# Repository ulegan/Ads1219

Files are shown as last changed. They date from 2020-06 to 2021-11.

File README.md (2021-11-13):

# Ads1219
A breakout board for the [ADS1219](https://www.ti.com/product/ADS1219) 24-bit AD-Converter.<br />
Size and pinout is the same as the popular ADS1x15 boards.
- Up to 1000Hz samplingrate
- Single or continuous conversion
- Single ended or differential inputs

pcb made with [KiCad](https://kicad.org/)

### Boards ordered from [OSHPARK](https://oshpark.com/)
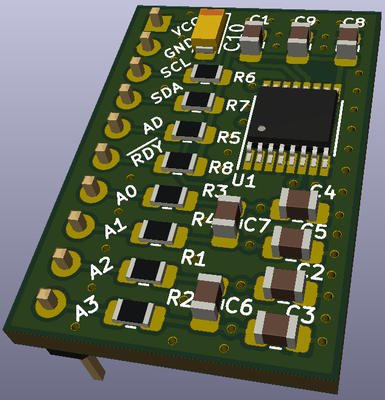
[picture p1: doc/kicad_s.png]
kicad rendering KiCad rendering
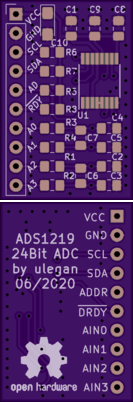
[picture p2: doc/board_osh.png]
preview OSHPARK preview
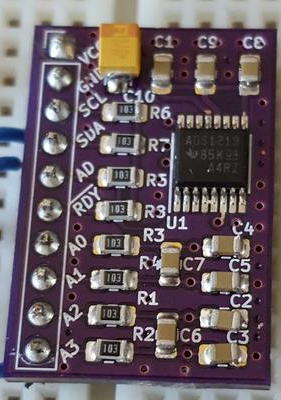
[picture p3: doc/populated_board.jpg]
first board populated board
  

### Diagramm 
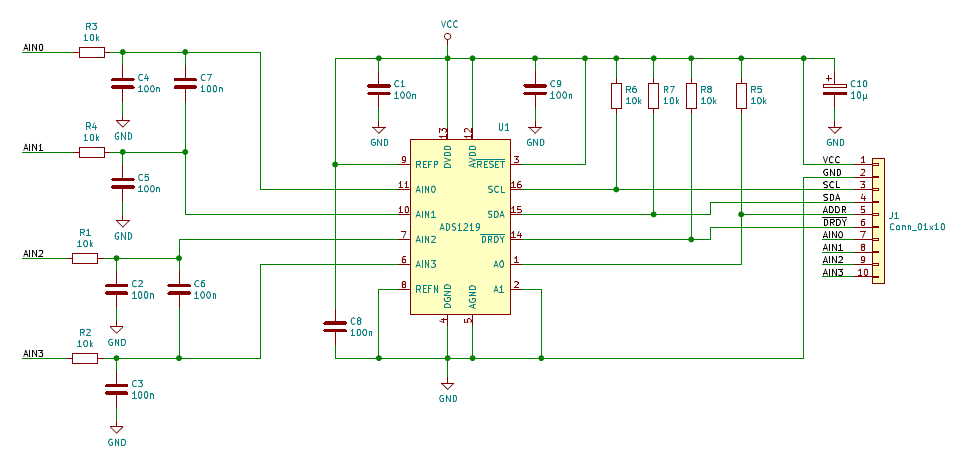
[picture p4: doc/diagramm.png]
Diagramm


If you want to use single-ended inputs, you should not use C6 and C7

### Libraries
I have written libraries for **C** and **Python** tested on a Raspberry-Pi

OM2220 wrote an [Arduino library](https://github.com/OM222O/ADS1219) for it <br />
and there is also one for [micropython](https://github.com/miketeachman/micropython-ads1219) that I have not tested yet.<br />

All libraries use the I²C-address 0x40 by default, so you have to connect the ADDR-Pin to GND, or use 0x41 in the constructor.

#### I²C-Addressing
The ADS1219 has two address-pins A0 and A1. <br />
A1 is always connected to GND, A0 has a pullup to VCC.<br />
So the I²C-ADDRESS defaults to 0x41. <br />
Four different addresses can be selected by connecting A0:

| ADDR connected to | Address |
| :--- |:---:|
| GND | 0x40 |
| VCC or open | 0x41 |
| SDA | 0x42 |
| SCL | 0x43 |

```c++

```

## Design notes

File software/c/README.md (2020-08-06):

### Prequisites
Install i2c-dev library for C
	apt-get install libi2c-dev
	
### Restrictions
Usage of RDY-pin is not supported yet

### Functions
**ads_config( mux, gain, datarate, mode, ref )**
configures the ADS1219 operating mode. Use with the constants below<br />
**ads_reset( )** resets ADS1219<br />
**ads_start( )** starts a single conversion, or starts continuous conversions<br />
**ads_powerdown( )** starts powerdown-mode, also stops conversions in continuous-mode<br />
**ads_ready( )** returns True if a new conversion result is ready 
*(reads status-register)*<br />
**ads_waitForResult( )** waits for a new conversion-result
	
### Constants to use in ads_config()
#### Constants for the input multiplexer
* **MUX_DIF_01** selects differential input pos=pin0 neg=pin1
* **MUX_DIF_23** selects differential input pos=pin2 neg=pin3
* **MUX_DIF_12** selects differential input pos=pin1 neg=pin2
* **MUX_SNG_0** selects single-ended input on pin0
* **MUX_SNG_1** selects single-ended input on pin1
* **MUX_SNG_2** selects single-ended input on pin2
* **MUX_SNG_3** selects single-ended input on pin3
* **MUX_SHORT** selects shorted differential inputs to meassure offset
#### Constants for gain selection
* **GAIN_1** input range +-2.048V with differential inputs and internal reference
* **GAIN_4** input range +-512mV with differential inputs and internal reference
#### Constants for selecting data rate
* **DR_20** sets data-rate to 20 samples per second
* **DR_90** sets data-rate to 90 samples per second
* **DR_330** sets data-rate to 330 samples per second
* **DR_1000** sets data-rate to 1000 samples per second
#### Constants for mode selection
* **MODE_SINGLESHOT** selects singleshot mode
* **MODE_CONTINUOUS** selects continuous mode
#### constants for selecting the reference voltage
* **VREF_INTERNAL** selects the internal 2.048V reference
* **VREF_EXTERNAL** selects an external reference 
### Example program test.c
````C
#include "ads1219.h"

int main() {
	int res;
	if( ( res = i2c_init(i2c_addr))<0 ) 
		printf("init failed with %d\n", res);
	ads_reset();
	ads_config(MUX_SHORT, GAIN_1, DR_20, MODE_CONTINUOUS, VREF_INTERNAL);
	ads_start();
	while(1) {
		ads_waitForReady();
		printf("%d  %d\n", time(0), ads_result());
	}
}
````
#### Compile example program with:
    cc test.c ads1219.c -otest -li2c

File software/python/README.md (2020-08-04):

### Prequisites
Install smbus2.py, because ADS1219 uses repeated start conditions, that are not supported with smbus

    pip3 install smbus2

### Constructor
**ADS1219( port=1, address=0x40, rdyPin=0 )** constructor<br />
* **port** is the I2C-port defaults to I2C1 on Pin3 (SDA) and Pin5 (SCL) on Raspberry Pi's
* **address** is the I2C-address
* **rdyPin** is the optional RDY-Pin, default: not connected

### Functions
**config( mux=MUX_DIF_01, gain=GAIN_1, datarate=DR_20, mode=MODE_SINGLESHOT, ref=VREF_INTERNAL )**
configures the ADS1219 operating mode. Use with the constants below<br />
**reset( )** resets ADS1219<br />
**start( )** starts a single conversion, or starts continuous conversions<br />
**powerdown( )** starts powerdown-mode, also stops conversions in continuous-mode<br />
**ready( )** returns True if a new conversion result is ready 
*(reads status-register)*<br />
**waitForResult( )** waits for a new conversion-result
*(uses **rdyPin** if given in constructor, or reads the status register)*<br />
**result( )** reads conversion result<br />
**callback( callbackFunction )** sets a callback function that is called, when a new conversion result is ready
*(only available if a **rdyPin** is given in the constructor)*

### Constants to use in config()
#### Constants for the input multiplexer
* **MUX_DIF_01** selects differential input pos=pin0 neg=pin1
* **MUX_DIF_23** selects differential input pos=pin2 neg=pin3
* **MUX_DIF_12** selects differential input pos=pin1 neg=pin2
* **MUX_SNG_0** selects single-ended input on pin0
* **MUX_SNG_1** selects single-ended input on pin1
* **MUX_SNG_2** selects single-ended input on pin2
* **MUX_SNG_3** selects single-ended input on pin3
* **MUX_SHORT** selects shorted differential inputs to meassure offset
#### Constants for gain selection
* **GAIN_1** input range +-2.048V with differential inputs and internal reference
* **GAIN_4** input range +-512mV with differential inputs and internal reference
#### Constants for selecting data rate
* **DR_20** sets data-rate to 20 samples per second
* **DR_90** sets data-rate to 90 samples per second
* **DR_330** sets data-rate to 330 samples per second
* **DR_1000** sets data-rate to 1000 samples per second
#### Constants for mode selection
* **MODE_SINGLESHOT** selects singleshot mode
* **MODE_CONTINUOUS** selects continuous mode
#### constants for selecting the reference voltage
* **VREF_INTERNAL** selects the internal 2.048V reference
* **VREF_EXTERNAL** selects an external reference 
### Examples
#### Read channel 0 in singleshot-mode
```python
from ADS1219 import ADS1219

ads=ADS1219()

ads.reset()
ads.config(ads.MUX_SNG_0, ads.GAIN_1, ads.DR_20, ads.MODE_SINGLESHOT, ads.VREF_EXTERNAL)
ads.start()
ads.waitForResult()
print(ads.result())
```
#### Read 100 samples betweeen inputs 0 and 1 in continuous-mode
```python
from ADS1219 import ADS1219

ads=ADS1219()

ads.reset()
ads.config(ads.MUX_DIF_01, ads.GAIN_1, ads.DR_20, ads.MODE_CONTINUOUS, ads.VREF_EXTERNAL)
ads.start()
for i in range(100):
	ads.waitForResult()
	print(ads.result())
```
#### Read for 5 seconds, using RDY-pin and callback
```python
from ADS1219 import ADS1219
from time import sleep

ads=ADS1219( rdyPin=4 )

def doSomething():
	v = ads.result()
	print( v )

ads.reset()
ads.config(ads.MUX_DIF_01, ads.GAIN_1, ads.DR_20, ads.MODE_CONTINUOUS, ads.VREF_EXTERNAL)
ads.callback( doSomething )
ads.start()
sleep(5)
```

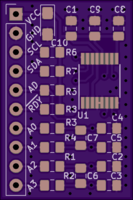
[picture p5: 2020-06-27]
doc/boardTop.png

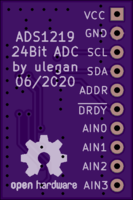
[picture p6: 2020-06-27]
doc/boardBottom.png

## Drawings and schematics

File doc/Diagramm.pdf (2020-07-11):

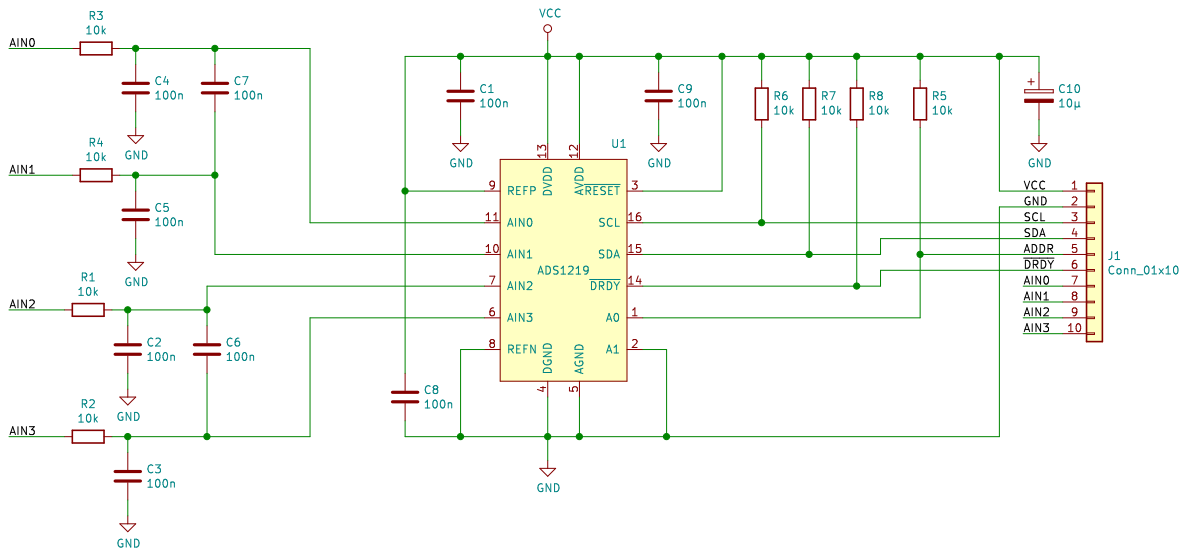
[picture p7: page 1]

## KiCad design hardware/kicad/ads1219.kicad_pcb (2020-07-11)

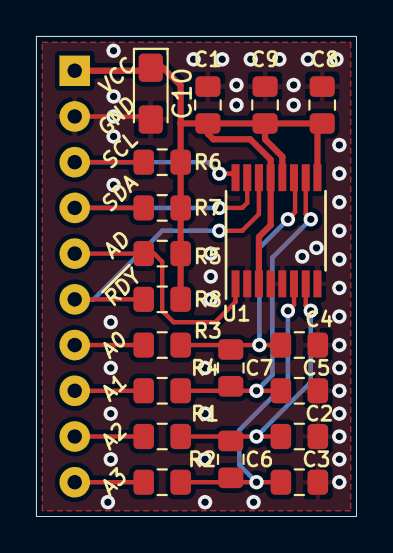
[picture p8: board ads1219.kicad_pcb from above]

Board: 2 copper layers, 17.8 x 26.7 mm, 20 parts (1 on the bottom side), 14 nets.

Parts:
C1, C2, C3, C4, C5, C6, C7, C8, C9: 100n; C_0805_2012Metric_Pad1.15x1.40mm_HandSolder
C10: 10µ; CP_EIA-3216-10_Kemet-I_Pad1.58x1.35mm_HandSolder
J1: Conn_01x10; PinHeader_1x10_P2.54mm_Vertical
R1, R2, R3, R4, R5, R6, R7, R8: 10k; R_0805_2012Metric_Pad1.15x1.40mm_HandSolder
U1: ADS1219; TSSOP-16_4.4x5mm_P0.65mm

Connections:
/ADDR: J1.5, R5.1, U1.1
/AIN0: J1.7, R3.2
/AIN1: J1.8, R4.2
/AIN2: J1.9, R1.2
/AIN3: J1.10, R2.2
/SCL: J1.3, R6.1, U1.16
/SDA: J1.4, R7.1, U1.15
/~DRDY: J1.6, R8.1, U1.14
GND: C1.2, C2.2, C3.2, C4.2, C5.2, C8.2, C9.2, C10.2, J1.2, U1.2, U1.4, U1.5, U1.8
unnamed: C2.1, C6.1, R1.1, U1.7
unnamed: C3.1, C6.2, R2.1, U1.6
unnamed: C4.1, C7.1, R3.1, U1.11
unnamed: C5.1, C7.2, R4.1, U1.10
VCC: C1.1, C8.1, C9.1, C10.1, J1.1, R5.2, R6.2, R7.2, R8.2, U1.3, U1.9, U1.12, U1.13

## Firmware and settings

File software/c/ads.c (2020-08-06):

#include "ads1219.h"
	
int i2c_handle;

int i2c_init(int addr) {
int handle;
    if( (handle = open("/dev/i2c-1",O_RDWR))<0 ) return -1;
    if( ioctl(handle, I2C_SLAVE, addr)<0 ) return -2; 
	i2c_handle = handle;
    return handle;
}
 
int write_command(const uint8_t cmd) {
	return i2c_smbus_write_byte(i2c_handle, cmd);
}
 
int read_registers(uint8_t reg, int size, uint8_t* buffer) {
    struct i2c_rdwr_ioctl_data work_queue;
    struct i2c_msg msg[2];
 
    work_queue.nmsgs = 2;
    work_queue.msgs = msg;
     
    work_queue.msgs[0].addr = i2c_addr;
    work_queue.msgs[0].len = 1;
    work_queue.msgs[0].flags = 0;
    work_queue.msgs[0].buf = &reg;
 
    work_queue.msgs[1].addr = i2c_addr;
    work_queue.msgs[1].len = size;
    work_queue.msgs[1].flags = I2C_M_RD;
    work_queue.msgs[1].buf = buffer;
     
    return ioctl(i2c_handle,I2C_RDWR,&work_queue);
}

void ads_config(uint8_t mux, uint8_t gain, uint8_t datarate, uint8_t mode, uint8_t ref) {
	uint8_t value = mux | gain | datarate | mode | ref;
	i2c_smbus_write_byte_data(i2c_handle, CMD_WREG, value);
}

uint8_t ads_ready() {
	uint8_t buffer[2];
	read_registers(CMD_RREG|4, 1, buffer);
	return buffer[0] & 0x80;
}

void ads_waitForReady() {
	while(!ads_ready()) usleep(1000);
}

int32_t ads_result() {
	uint8_t buffer[3];
	read_registers(CMD_RDATA, 3, buffer);
//	printf("\n%02x%02x%02x\n",buffer[0],buffer[1],buffer[2]);
	int32_t value = (buffer[0]&0x80 ? 0xff000000:0x00000000) | (buffer[0]<<16) | (buffer[1]<<8) | (buffer[2]);
	return value;
}

 

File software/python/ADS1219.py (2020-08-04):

#	Python driver for the Texas Instruments ADS1219 ADC
#	Tested with Raspberry PI

#	Copyright (c) 2020 Uwe Nagel

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
from smbus2 import SMBus, i2c_msg
import RPi.GPIO as GPIO
from time import sleep

class ADS1219:

	CMD_RESET = 0x06
	CMD_START_SYNC = 0x08
	CMD_POWERDOWN = 0x02
	CMD_RDATA = 0x10
	CMD_RREG = 0x20
	CMD_WREG = 0x40
	MUX_DIF_01 = 0x00
	MUX_DIF_23 = 0x20
	MUX_DIF_12 = 0x40
	MUX_SNG_0 = 0x60
	MUX_SNG_1 = 0x80
	MUX_SNG_2 = 0xa0
	MUX_SNG_3 = 0xc0
	MUX_SHORT = 0xe0
	GAIN_1 = 0x00
	GAIN_4 = 0x10
	DR_20 = 0x00
	DR_90 = 0x04
	DR_330 = 0x08
	DR_1000 = 0x0c
	MODE_SINGLESHOT = 0x00
	MODE_CONTINUOUS = 0x02
	VREF_INTERNAL = 0x00
	VREF_EXTERNAL = 0x01

	def write_command( self, cmd ):
		self.bus.write_byte( self.i2c_adr, cmd )

	def read_registers( self, reg, size ):
		write = i2c_msg.write( self.i2c_adr, [reg] )
		read  = i2c_msg.read( self.i2c_adr, size )
		self.bus.i2c_rdwr( write, read )
		return list( read )

	def start( self ):
		self.write_command( self.CMD_START_SYNC )

	def reset( self ):
		self.write_command( self.CMD_RESET )

	def powerdown( self ):
		self.write_command( self.CMD_POWERDOWN )

	def config( self, mux=MUX_DIF_01, gain=GAIN_1, datarate=DR_20, mode=MODE_SINGLESHOT, ref=VREF_INTERNAL ):
		value = mux | gain | datarate | mode | ref
		self.bus.write_byte_data( self.i2c_adr, self.CMD_WREG, value )

	def ready( self ):
		buffer = self.read_registers( self.CMD_RREG|4, 1 )
		return buffer[0] & 0x80
		
	def waitForResult( self ):
		if self.rdyPin>0:
			GPIO.wait_for_edge( self.rdyPin, GPIO.FALLING )
		else:
			while not self.ready():
				sleep(0.0005)

	def result( self ):
		buffer = self.read_registers( self.CMD_RDATA, 3 )
		value = (buffer[0]<<16) | (buffer[1]<<8) | (buffer[2])
		if value >= 0x800000:
			value = value-0x1000000
		return value

	def callback( self, callbackFunction ):
		GPIO.add_event_detect( self.rdyPin, GPIO.FALLING, callback=lambda _: callbackFunction() )

	def __init__( self, port=1, address=0x40, rdyPin=0 ):
#		print("_INIT_")
		self.i2c_adr = address  #0x40
		self.bus = SMBus( port, True )
		self.rdyPin = rdyPin
		if( rdyPin>0 ):
			GPIO.setmode( GPIO.BCM )
			GPIO.setup(rdyPin, GPIO.IN )

	def __enter__( self ):
#		print("_ENTER_")
		return self
		
	def __del__( self ):
#		print("_DEL_")
		self.bus.close()

	def __exit__( self, exc_type, exc_value, traceback ):
#		print("_EXIT_")
		self.bus.close()

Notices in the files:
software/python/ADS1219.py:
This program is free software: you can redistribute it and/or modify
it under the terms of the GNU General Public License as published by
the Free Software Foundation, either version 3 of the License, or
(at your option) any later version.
